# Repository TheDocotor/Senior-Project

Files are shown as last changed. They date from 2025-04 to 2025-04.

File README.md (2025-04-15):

# RC2 Ellipsometer Autoleveling

This repository contains all required documentation for the building and operation of an automated leveling system for in-situ temperature testing on the JA Woolham RC2 Ellipsometer.
Please refer to Ellipsometer_Technical_Design_Document.pdf for full write up of system.

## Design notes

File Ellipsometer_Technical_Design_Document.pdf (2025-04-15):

# Ellipsometer Automated Leveling System

### Technical Design Document

### Garrett Nadauld Ryan Enslow Weber State University Advisor: Dr. Mock

### March 31, 2025

## Contents

1 Introduction | 3
2 Scope | 3
3 Design Overview | 3
4 Testing | 7
5 Conclusion | 8
6 Appendices | 8

## Executive Summary

This project focuses on the design and development of an automated leveling system for the RC2 Ellipsometer, used in precision surface testing. Our primary goal is to reduce workload and speed up testing. The system uses a lookdown detector and servo motors, controlled by a ClearCore microcontroller, to automatically level the test sample.
By automating core functionalities and retaining manual control, our system reduces user workload while maintaining compatibility and precision. The apparatus is removable, integrates easily with existing test setups, and aims to provide a cost-effective alternative to commercial solutions.

## 1 Introduction

The Ellipsometer Automated Leveling System enhances precision and efficiency in aligning samples for ellipsometric measurements. Using a laser-based tilt detection system and servodriven screw adjustments, it minimizes human error and streamlines the alignment process for high-throughput and high-accuracy surface testing.

## 2 Scope

This document details the design of the automated leveling system, including requirements, constraints, design logic, hardware/software implementation, and testing. It excludes user operations and measurement procedures, which are documented separately in the user manual.

## 3 Design Overview

### 3.1 Requirements

Functional Requirements

- Detect sample tilt using a laser and 2D lateral-effect position sensor.
- Automatically adjust leveling screws via servo motors.
- Toggle between manual and automatic leveling modes.
- Interface with ClearCore and USB debugging.

Performance Requirements

- Achieve tilt correction within ±0.2 units in under 3 seconds.
- Maintain level without disrupting measurements.

Interface Requirements

- ClearCore GPIO compatibility.
- Toggle switch for mode selection.

### 3.2 Constraints

- Physical: Must mount externally, be removable, and avoid laser path interference.
- Cost: Total system budget under $2,400.
- Power: Operates from two 24V DC with step-down converters.
- Safety: Laser beam intensity attenuated via ND filter.
- Time: Completion within two academic semesters.

### 3.3 Dependencies

- External 120V AC power source
- Flat, reflective sample surface
- Microchip Studio with ClearCore SDK
- USB programming interface

### 3.4 Theory of Operation

A 635 nm laser reflects off the sample surface onto a ThorLabs PDP90A lateral-effect sensor. The sensor detects displacement from level, which the ClearCore controller uses to compute necessary corrections. It sends commands to ClearPath servo motors that adjust the sample’s leveling screws via a belt drive.

### 3.5 Design Alternatives

### 3.5.1 Motor Selection

Stepper motors were initially considered due to their low cost and simplicity. However, they were ultimately rejected because they lack closed-loop feedback and are prone to missed steps, especially under load. To ensure reliable and precise alignment, servo motors with integrated control logic were selected instead.
The chosen ClearPath-SD servo motors feature a Step & Direction interface compatible with the Teknic ClearCore controller. These servos include automatic tuning capabilities that optimize performance for the specific application and load. Their integrated design eliminates the need for separate motor driver wiring, reducing system complexity and potential failure points.
Other advantages include:

- Closed-loop positioning, which eliminates concerns about missed steps
- Whisper-quiet operation, avoiding the audible whine typical of stepper motors

### 3.5.2 Sensor Selection

Quadrant Position Photodiode Detectors (QPDs), such as the ThorLabs PDQ80A and PDQ30C, were considered as potential alternatives due to their ability to determine beam displacement by comparing photocurrent across segmented regions. However, these detectors rely on intensity profiling and segmented detection, which inherently limits their resolution and introduces nonlinearity, particularly near quadrant boundaries.
The ThorLabs PDP90A 2D lateral-effect sensor was ultimately selected for its superior linearity, continuous position output, and cost-effective design. Unlike QPDs, the PDP90A operates using a tetra-lateral position-sensing mechanism, where photocurrent is distributed proportionally across a resistive layer and four corner-mounted electrodes. This “pincushion” design enables highly linear performance across the 9 mm × 9 mm active area, with accuracy comparable to more expensive duo-lateral sensors.
Additional advantages of the PDP90A include:
- Analog output in both X and Y axes, ideal for continuous feedback loops
- High resolution suitable for precision optical alignment tasks
- Compatibility with the 635 nm laser wavelength used in the system
- Cost-effective alternative to duo-lateral designs due to simplified structure

These characteristics made the PDP90A an optimal choice for accurate and responsive tilt detection in the automated leveling application.

### 3.5.3 Laser Selection

The PL204 laser module from ThorLabs was selected as the light source for this system. The key factors influencing this decision were:

- Cost: The PL204 is a cost-effective, off-the-shelf component with sufficient beam quality and output power for position-sensing applications.
- Wavelength Compatibility: Operating at 635 nm, the laser falls well within the operating range of the PDP90A lateral-effect sensor, which supports wavelengths from 320 nm to 1100 nm. This ensures reliable detection and signal strength without oversaturating the sensor.

An alternative considered was a tunable laser source. Such a laser would have allowed precise adjustment of output power and wavelength to potentially improve the resolution and signal-to-noise ratio of the PDP90A. However, tunable lasers are significantly more expensive and complex to integrate, and the marginal gains in resolution did not justify the increased cost and design complexity for this application.
The PL204 thus provided a practical balance between performance, simplicity, and cost.

### 3.6 Software

The program SeniorProject.cpp implements an automatic leveling system for a J.A. Woollam RC2 Ellipsometer. The system uses a lateral effect position-sensing detector and a laser to monitor the position of the beam reflected from the sample surface. Based on the beam’s displacement, the program computes if the test bed has deviated from its leveled position. If it has, two ClearCore-controlled stepper motors make precise adjustments in the X and Y directions to restore the correct alignment.
The software runs continuously on the Teknic ClearCore microcontroller. It averages voltage readings from three analog inputs (X, Y, and SUM) and determines whether any deviation from a previously recorded level position exceeds a defined tolerance threshold. When the “leveling” switch is turned on, the system records the current position as the baseline and proceeds to adjust the motor position if deviations are detected. The program alternates between checking X and Y directions, with a 75 ms delay between each sample set.
Safety mechanisms include automatic motor alert handling and LED indicators to warn if the laser signal is lost. The system disables motors when not actively leveling, allowing manual adjustment.

### 3.7 Function Descriptions

### main()

The main function initializes the hardware configuration and enters a loop that:

- Reads analog voltages from three ClearCore connectors.
- Converts these voltages to floating-point values for processing.
- Averages 10 samples to reduce noise.
- If the system is in ”leveling” mode, it:

– Enables the motors.

– Sets a reference level position if it’s the first loop.

– Checks if the laser is off the sensor (low SUM voltage).

– If the sample has shifted beyond X or Y tolerance, moves the motors accordingly.

- If not leveling, it disables the motors.

### MoveDistanceX(int32 t distance)

This function moves the X-axis motor by a specified number of step pulses. It:

- Checks if there is a motor alert and handles it.
- Sends a move command to the motor.

- Waits for the motor’s HLFB (High-Level Feedback) to assert that the move is complete.

This function enables precise micro-adjustments based on laser deviations in the X direction.

### MoveDistanceY(int32 t distance)

Same as MoveDistanceX, but for the Y-axis motor. Ensures the Y adjustment happens only if it is safe to do so.

### HandleAlertsX()

This function resets fault conditions for the X-axis motor. It:

- Disables the motor momentarily.
- Waits 10 ms.
- Re-enables the motor and clears all alerts.

Used to recover from faults like overload or signal loss.

### HandleAlertsY()

Identical in structure to HandleAlertsX(), but for the Y motor. Keeps the system in a recoverable state after motor errors.

### 3.8 Power System

- Laser Power: The PL204 laser module requires a regulated 5V supply. A DC-DC converter is used to step down from the 24V system voltage to 5V.
- Sensor Power: The PDP90A sensor requires a split supply of ±5V. A dedicated DC-DC converter is used to generate this bipolar voltage from a 24V input.
- Motor Isolation: The ClearPath-SD motors are powered by a separate 24V power supply, isolated from the logic and sensor power domains. This prevents noise and back EMF from interfering with sensitive analog circuitry.

## 4 Testing

Test | Procedure | Expected Result | Requirement Verified
Sensor Detection | Manually tilt sample | Beam offset de-tected | Functional

Motor Adjustment | Enable auto with tilt present | Leveling completes in ¡3s | Performance
Manual Switch | Flip toggle to manual | Disables auto mode | Interface
System Safety | Power cycle during test | Motors halt safely | Constraint

## 5 Conclusion

The system meets all major design requirements, providing consistent and quick leveling without affecting the operation of the ellipsometer. While not being able to level maintain the sample level within 0.2 units it still provides a significant increase in performance compared to results without the system. The servo-based mechanism and ClearCore controller delivered reliable performance in lab testing. Future improvements include GUI integration, wireless controls, using the software level for adjustments, and beam positioning testing.

## 6 Appendices

### 6.1 Wiring Diagram

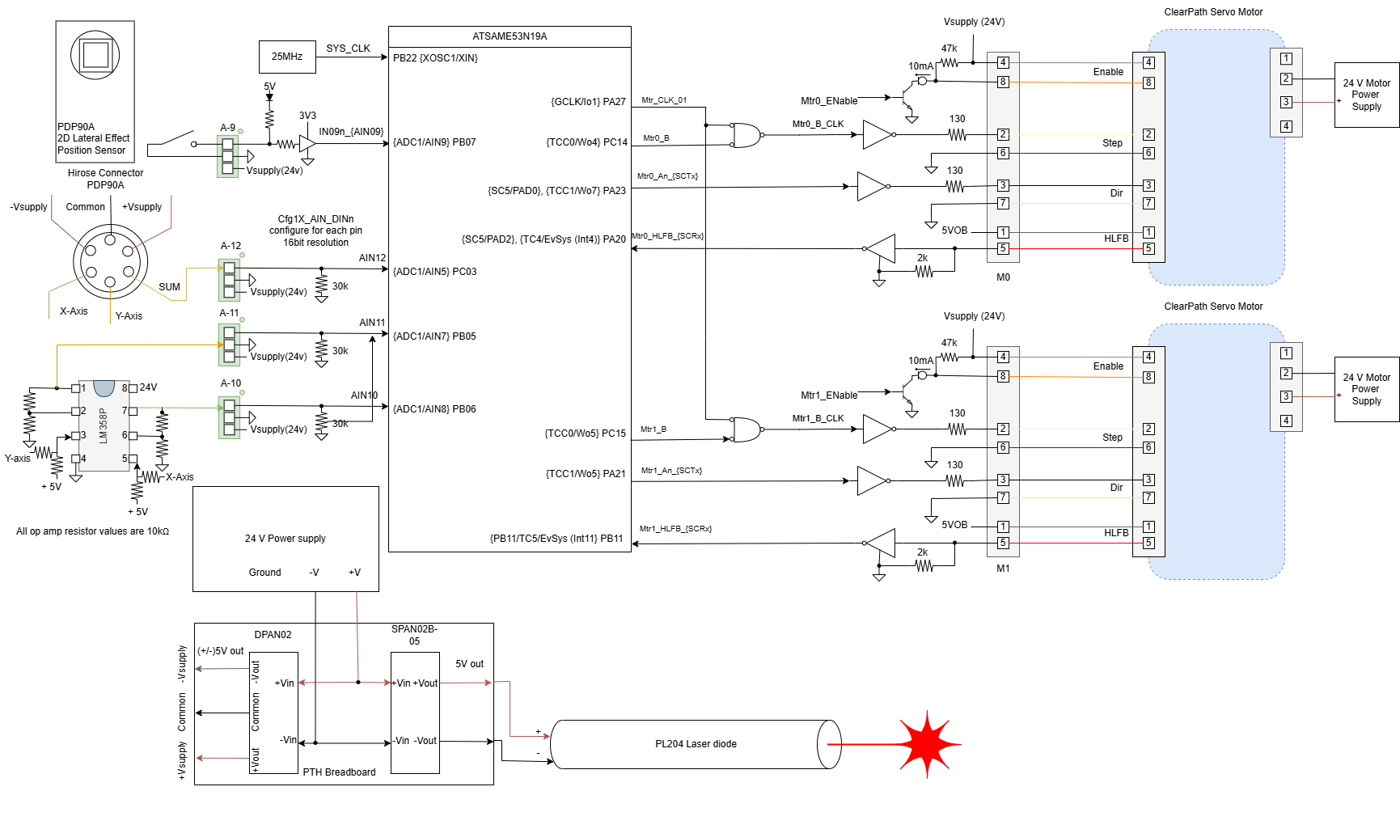
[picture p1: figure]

Figure 1: Full System Wiring Diagram

### 6.2 Source Code

All source code can be found at: https://github.com/TheDocotor/Senior-Project

### 6.2.1 C++

- SeniorProject.cpp (main) - Used in normal operation of leveling. No serial output.
- SeniorProject.cpp (SerialPrint) - Used in conjunction with EllipData.py to send voltage information from clear core and compiles data into a CSV that chan be processed by SerialData.py.

### 6.2.2 Python

- EllipData.py - Used to gather the serial data from the ClearCore. Compiles the data into a CSV that can be processed by SerialData.py
- CompleteEase.py - Used to plot the level data as seen in the CompleteEase Software. Useful to average multiple runs or compare runs to original alignment prior to installation of the system.
- SerialData.py - Used to plot the position on the sensor based on data collected by EllipData.py. Also provides standard deviation, mean and max deviation from center.

### 6.3 CAD Files

The following CAD files are included in the project archive and can be found at: https://github.com/TheDocotor/Senior-Project

- TopMount.stl – 3D-printed bracket for sensor and laser
- TopMount.step – 3D-printed bracket for sensor and laser
- MotorMountX.stl – Servo motor mount for X
- MotorMountX.step – Servo motor mount for X
- MotorMountY.stl – Servo motor mount for Y
- MotorMountY.step – Servo motor mount for Y
- AdjustmentKnob.stl – Cap for adjustment knobs
- AdjustmentKnob.step – Cap for adjustment knobs

### 6.4 Component Datasheets

All data sheets are included in the project archive and can be found at: https://github.com/TheDocotor/Senior-Project

### 6.5 Bill of Materials

Component | Part Number | Qty | Notes
PDP90A Sensor | PDP90A | 1 | Lateral-effect sensor
PL204 Laser | PL204 | 1 | 635 nm beam
Absorptive ND Filter | NE510A | 1 | 25% light transmission
DC-DC Converter (5V) | SPAN02B-05 | 1 | 24V to 5V
DC-DC Converter (±5V) | DPBW03F-05 | 1 | 24V to ±5V
ClearCore Controller | CLCR-4-13 | 1 | Motion and I/O control
Atmel-ICE Debugger | ATATMEL-ICE-BASIC | 1 | Debugger for ClearCore
Atmel-ICE to ClearCore | TC2030-CTX-LEMTA | 1 | Cable for debugger
ClearPath Servo Motors | CPM-SDSK-2310D-ELN | 2 | Level adjustments
Power Supply | LRS-150-24 | 2 | 24V DC supplies
Op-Amp | 296-1395-5-ND | 1 | Sensor voltage offset
3D Printed Mounts | – | 5 | Sensor, laser, motor, and
adjustment knob models
2-Pin Molex Plug | WM20244-ND | 2 | Modular | connector | for
| | | laser
2-Pin Molex RCPT | WM13486-ND | 2 | Companion to 2-pin plug
4-Pin Molex Plug | WM16259-ND | 3 | For motor power cabling
4-Pin Molex RCPT | WM16165-ND | 1 | Companion to 4-pin male
8-Pin Molex Plug | WM26395-ND | 5 | Motor | control | to
| | | ClearCore
8-Pin Molex RCPT | WM13488-ND | 1 | Companion to 8-pin male
Terminal Block Plugs | CC-3TERM-PLUG-10PC | 5 | Companion to 8-pin male
Switch | – | 2 | Toggles for power and lev-
eling control
Hirose RCPT (F) 6P | HR1594-ND | 1 | For sensor to enclosure
Drive Belt | 124L050NG | 2 | Belt to connect motor
shaft to adjustment knob
Timing Pulley | APB13L050BF-375 | 2 | Conenction point for the
motor shaft
Power Receptacle | CCM1784-ND | 1 | Power cable receptacle
Power Cable | Q988-ND | 1 | Cable for wall outlet

Table 2: Bill of Materials

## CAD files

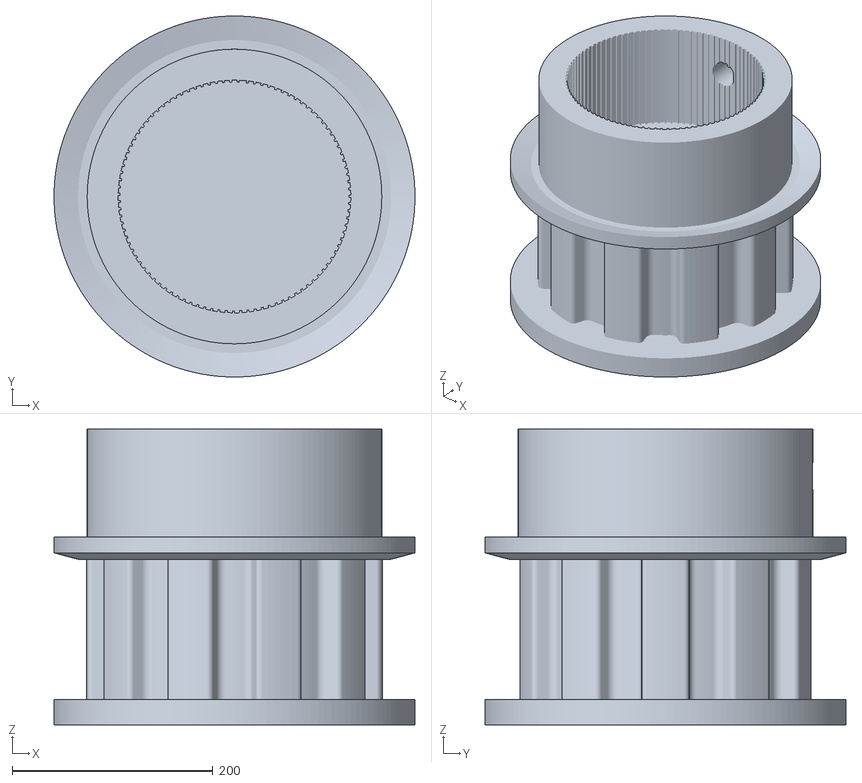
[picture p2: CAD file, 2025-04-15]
3Dprint files/AdjustmentKnob.stl
360.0 x 360.0 x 294.8

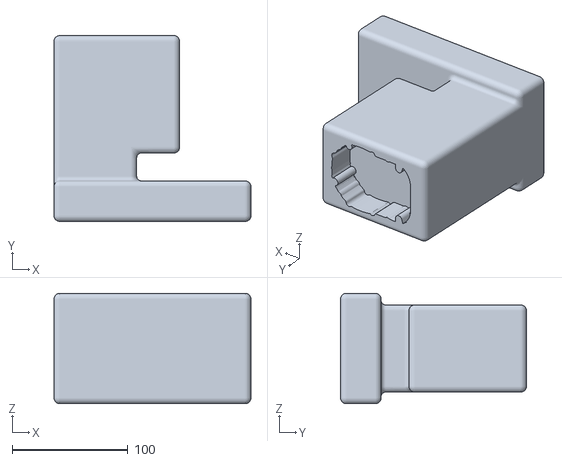
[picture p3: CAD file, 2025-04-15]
3Dprint files/MotorMountY.stl
170.0 x 160.4 x 95.2

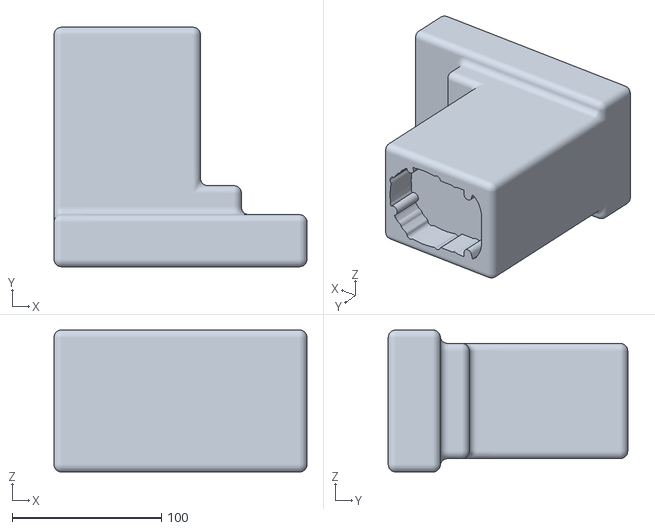
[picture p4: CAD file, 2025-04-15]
3Dprint files/MotorMountX.stl
169.7 x 160.7 x 95.2

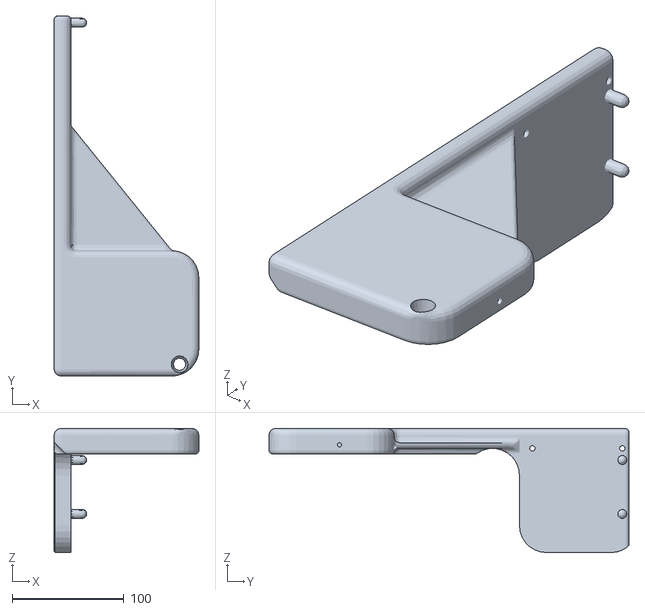
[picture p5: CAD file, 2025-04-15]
3Dprint files/TopMount.stl
129.6 x 322.2 x 111.0

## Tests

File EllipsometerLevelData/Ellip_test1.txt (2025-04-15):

Parameters vs. Time
Time (min.)	AlignX	AlignY	Temperature(C)
0.118583	-0.041280	-0.026336	24.836016	
0.172583	0.020837	-0.021236	25.014530	
0.226583	0.045690	0.034902	25.296223	
0.280583	0.085720	0.096434	25.885847	
0.334617	0.109744	0.151967	26.524569	
0.388617	0.189993	0.230251	27.327288	
0.442650	0.228375	0.313507	28.179588	
0.496650	0.295306	0.290474	29.137653	
0.550683	0.395386	0.091753	30.176928	
0.604717	0.393161	0.128371	31.230230	
0.658683	0.395943	0.143892	32.255962	
0.712683	0.397930	0.184818	33.403984	
0.766717	0.429667	0.263335	34.405983	
0.820683	0.286139	-0.026264	35.376667	
0.874717	0.331988	-0.093079	36.448162	
0.928517	0.360934	-0.028123	37.490608	
0.982317	0.417613	0.018809	38.557739	
1.036183	0.431605	-0.058537	39.533081	
1.090083	0.495320	-0.231804	40.532272	
1.144117	0.502457	-0.158535	41.504047	
1.198117	0.536670	-0.150594	42.480343	
1.252117	0.549993	-0.108000	43.497299	
1.306117	0.566278	-0.049375	44.394398	
1.360183	0.457136	-0.012867	45.321918	
1.414150	0.484191	-0.161352	46.321804	
1.468183	0.485045	-0.334342	47.276814	
1.522217	0.529164	-0.299895	48.199162	
1.576217	0.524435	-0.207020	49.158245	
1.630250	0.596894	-0.150165	50.118965	
1.684250	0.479925	-0.168618	50.968613	
1.738250	0.420639	-0.176686	51.953495	
1.792317	0.456555	-0.390947	52.935402	
1.846117	0.502611	-0.399960	53.884766	
1.899950	0.519346	-0.318151	54.742939	
1.953883	0.516156	-0.271888	55.674828	
2.007917	0.487114	-0.267040	56.497173	
2.061783	0.386563	-0.198937	57.497993	
2.115817	0.412487	-0.426013	58.301781	
2.169850	0.440590	-0.488537	59.202728	
2.223850	0.462063	-0.416323	60.109184	
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

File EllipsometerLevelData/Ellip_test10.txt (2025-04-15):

Parameters vs. Time
Time (min.)	AlignX	AlignY	Temperature(C)
0.168117	-0.011810	0.001451	24.131662	
0.222150	-0.006528	0.029344	24.490301	
0.276183	-0.044197	0.056674	24.938715	
0.330183	-0.056247	0.091909	25.522610	
0.384217	-0.008409	0.138111	26.258095	
0.438217	0.072713	0.105040	26.930157	
0.492217	-0.070123	0.145629	28.002691	
0.546250	-0.019005	-0.068894	28.866596	
0.600250	0.036046	-0.045884	29.905478	
0.654283	0.054328	-0.129453	30.854378	
0.708317	-0.064122	-0.258034	32.006828	
0.762317	-0.030392	-0.189520	32.986050	
0.816383	0.048420	-0.145151	34.075123	
0.870383	-0.071720	-0.125145	35.070518	
0.924417	-0.063865	-0.418252	36.225433	
0.978450	-0.166068	-0.363490	37.162262	
1.032450	-0.112328	-0.294412	38.124954	
1.086483	-0.099591	-0.430787	39.207615	
1.140450	-0.042349	-0.510560	40.190948	
1.194483	-0.108072	-0.486803	41.127972	
1.248517	-0.124357	-0.447834	42.130466	
1.302583	-0.096240	-0.651262	43.139202	
1.356650	-0.105625	-0.880548	44.017303	
1.410650	-0.251906	-0.802809	45.038170	
1.464683	-0.227095	-0.780231	46.062355	
1.518483	-0.236412	-0.987779	46.964535	
1.572317	-0.210413	-1.046481	47.967842	
1.626150	-0.383966	-1.397967	48.803471	
1.680183	-0.425216	-1.260316	49.796967	
1.734117	-0.380085	-1.224725	50.692398	
1.788050	-0.324533	-1.142400	51.627678	
1.842050	-0.378494	-1.135248	52.478645	
1.896083	-0.444369	-1.126213	53.482811	
1.949917	-0.510781	-1.078143	54.453556	
2.003750	-0.537672	-0.906426	55.338276	
2.057617	-0.492028	-0.853576	56.233845	
2.111617	-0.460295	-0.837870	57.061295	
2.165650	-0.439806	-0.850249	57.997799	
2.219783	-0.379291	-0.693380	58.990204	
2.273817	-0.404685	-0.758148	59.854618	
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

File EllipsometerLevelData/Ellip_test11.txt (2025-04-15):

Parameters vs. Time
Time (min.)	AlignX	AlignY	Temperature(C)
0.168583	-0.046639	-0.376566	20.884941	
0.222450	-0.041730	-0.349978	21.162317	
0.276417	-0.001431	-0.278168	21.518782	
0.330417	0.038545	-0.223533	22.094357	
0.384483	0.063708	-0.159545	22.917393	
0.438517	0.133346	-0.065030	23.665125	
0.492517	0.035776	-0.043938	24.598125	
0.546517	0.053317	0.023088	25.586304	
0.600517	0.118323	0.109434	26.561781	
0.654583	0.158599	0.137310	27.599186	
0.708583	0.038523	-0.118925	28.714796	
0.762583	-0.062618	-0.378510	29.634850	
0.816650	0.022626	-0.171334	30.757421	
0.870650	0.151670	-0.004082	31.759705	
0.924683	0.196825	0.090223	32.845123	
0.978817	0.165235	0.035145	33.888222	
1.032817	0.158794	0.043298	34.971466	
1.086817	0.229893	0.129744	35.921383	
1.140850	0.105978	-0.200749	36.998730	
1.194883	0.137041	-0.111148	37.975357	
1.248783	0.137578	-0.084488	38.939793	
1.302850	0.212065	-0.040451	39.980690	
1.356883	0.214735	0.027018	40.910282	
1.410883	0.232494	0.117401	41.782413	
1.464883	0.233183	0.207164	42.756306	
1.518917	0.263842	0.276724	43.788090	
1.572917	0.323576	0.109497	44.705631	
1.626917	0.339388	0.194124	45.713520	
1.680950	0.384755	0.211036	46.629547	
1.734983	0.294094	0.277594	47.503315	
1.789083	0.323616	0.286995	48.505264	
1.843083	0.305321	0.162863	49.377228	
1.897083	0.328178	0.215307	50.297901	
1.951083	0.258381	0.117444	51.302830	
2.005117	0.155571	0.015098	52.160259	
2.059117	0.188302	0.123254	53.103508	
2.113117	0.253333	0.187550	54.007843	
2.167150	0.274996	0.063613	54.915260	
2.221183	0.293713	-0.089819	55.800106	
2.275183	0.343788	0.085302	56.771717	
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

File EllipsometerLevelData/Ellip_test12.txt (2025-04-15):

Parameters vs. Time
Time (min.)	AlignX	AlignY	Temperature(C)
0.167683	0.067166	0.083648	23.120749	
0.221683	0.099483	0.093399	23.369642	
0.275650	0.118718	0.118501	23.757235	
0.329683	0.154895	0.178274	24.320704	
0.383683	0.220688	0.250243	25.049406	
0.437717	0.275300	0.258517	25.837414	
0.491717	0.297653	-0.060186	26.783432	
0.545750	0.330778	-0.161729	27.773209	
0.599783	0.354492	-0.043041	28.722492	
0.653783	0.262545	0.019468	29.715990	
0.707783	0.315992	0.082061	30.708815	
0.761850	0.381151	0.170664	31.884439	
0.815850	0.385087	-0.091623	32.818520	
0.869883	0.400611	-0.013517	33.989388	
0.923883	0.326587	0.032991	34.935841	
0.977883	0.350955	0.109889	36.012627	
1.031917	0.256558	0.171326	36.992962	
1.085917	0.260346	0.175757	37.986538	
1.139783	0.320190	-0.077792	39.035965	
1.193617	0.361817	0.005636	40.099243	
1.247450	0.340193	0.060590	41.077709	
1.301383	0.257872	0.131732	41.973297	
1.355383	0.282924	0.251629	42.978252	
1.409383	0.341448	0.022576	43.933132	
1.463383	0.356389	0.061620	44.911144	
1.517383	0.397805	0.081188	45.806206	
1.571283	0.201648	-0.137315	46.694366	
1.625317	0.216240	-0.028492	47.663288	
1.679317	0.058627	0.018462	48.621838	
1.733350	0.098453	-0.143214	49.623798	
1.787150	0.134544	-0.148360	50.474148	
1.841017	0.163277	-0.045786	51.457523	
1.894917	0.221606	0.011050	52.319489	
1.948850	0.262482	-0.039665	53.241241	
2.002850	0.091184	-0.224139	54.193779	
2.056883	0.076237	-0.112077	55.162113	
2.110883	0.198861	-0.051518	55.998070	
2.164717	0.112765	0.081392	56.849998	
2.218550	-0.012815	0.101781	57.758308	
2.272417	-0.167110	0.133754	58.739014	
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

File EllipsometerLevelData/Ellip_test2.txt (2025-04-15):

Parameters vs. Time
Time (min.)	AlignX	AlignY	Temperature(C)
0.168550	0.064122	0.044254	23.076591	
0.222550	0.084154	0.069582	23.364233	
0.276583	0.096145	0.118140	23.672337	
0.330583	0.168860	0.189502	24.302608	
0.384583	0.195827	0.257248	25.106260	
0.438583	0.227606	0.325688	25.875063	
0.492583	0.290378	0.416597	26.773712	
0.546583	0.311054	0.470335	27.701771	
0.600583	0.384512	0.590589	28.658625	
0.654617	0.405680	0.656004	29.751350	
0.708617	0.464308	0.715677	30.836828	
0.762650	0.505908	0.295842	31.893223	
0.816650	0.500468	0.393966	32.927197	
0.870683	0.552007	0.444180	34.018406	
0.924717	0.506079	0.517580	35.065228	
0.978750	0.457472	0.593879	35.991074	
1.032750	0.447968	0.676628	37.085220	
1.086783	0.522618	0.755370	38.086594	
1.140783	0.460573	0.847435	39.091526	
1.194783	0.374429	0.913129	40.006828	
1.248617	0.359926	0.790073	41.054150	
1.302417	0.426413	0.607261	42.035633	
1.356250	0.437331	0.648894	42.999187	
1.410250	0.522175	0.763229	43.881397	
1.464283	0.538267	0.567326	44.904099	
1.518250	0.390486	0.551536	45.884445	
1.572250	0.359735	0.642182	46.859360	
1.626317	0.431231	0.647077	47.723289	
1.680317	0.420001	0.723394	48.708366	
1.734350	0.476617	0.757418	49.611774	
1.788350	0.521664	0.608051	50.630070	
1.842350	0.571742	0.532589	51.493752	
1.896350	0.557687	0.615059	52.484177	
1.950350	0.443749	0.694331	53.339653	
2.004350	0.411256	0.501339	54.241287	
2.058350	0.432278	0.382363	55.134014	
2.112383	0.427113	0.399191	56.039650	
2.166250	0.487631	0.523825	57.035408	
2.220083	0.532069	0.590680	57.783031	
2.273917	0.523078	0.663774	58.715611	
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

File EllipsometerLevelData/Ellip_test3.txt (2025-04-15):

Parameters vs. Time
Time (min.)	AlignX	AlignY	Temperature(C)
0.167883	0.059796	-0.014691	23.007935	
0.221883	0.040957	0.020164	23.400824	
0.275917	0.080487	0.055859	23.930487	
0.329917	0.138778	0.117553	24.467409	
0.383917	0.188876	0.171581	25.170792	
0.437917	0.222484	0.257854	26.044857	
0.491950	0.308227	0.317970	27.017944	
0.545950	0.340746	0.385676	27.969851	
0.599983	0.346464	0.414496	29.017851	
0.653983	0.385103	0.474481	30.023184	
0.707983	0.387339	0.569224	31.035904	
0.761983	0.293574	0.577176	32.113567	
0.815950	0.316778	0.618829	33.130001	
0.869983	0.345379	0.651212	34.102303	
0.924017	0.360201	0.696558	35.217216	
0.978050	0.392810	0.732926	36.271786	
1.032050	0.428314	0.775259	37.293545	
1.086083	0.201085	0.765618	38.332333	
1.140117	0.260594	0.820848	39.280319	
1.194117	0.268870	0.866119	40.345001	
1.248117	0.249264	0.878686	41.275478	
1.302117	0.276686	0.948887	42.276386	
1.356150	0.141603	0.961982	43.239941	
1.410150	0.075218	0.981680	44.184528	
1.464183	0.138480	1.003076	45.123096	
1.518183	0.188208	1.035988	46.003750	
1.571983	0.185533	1.051620	47.054279	
1.625783	0.225736	1.096398	47.964714	
1.679583	0.268127	1.162743	48.864876	
1.733683	0.253632	1.211878	49.849255	
1.787650	0.290676	1.281211	50.741539	
1.841617	0.343024	1.349752	51.699059	
1.895550	0.367067	1.217065	52.598358	
1.949583	0.222444	0.955607	53.468552	
2.003583	0.230825	1.028350	54.449013	
2.057417	0.207331	1.094818	55.328953	
2.111250	0.266170	1.008512	56.277622	
2.165117	0.281910	0.627894	57.197071	
2.219183	0.307585	0.689762	58.060802	
2.273250	0.329247	0.819358	58.979935	
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

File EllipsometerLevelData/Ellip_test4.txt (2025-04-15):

Parameters vs. Time
Time (min.)	AlignX	AlignY	Temperature(C)
0.168117	-0.159759	-0.051092	23.545778	
0.222117	-0.121864	-0.006964	23.853886	
0.276117	-0.039485	0.041802	24.291838	
0.330183	-0.005436	0.122777	24.952137	
0.384183	0.038613	0.179799	25.692701	
0.438217	0.090251	0.224776	26.424063	
0.492217	0.142805	0.199326	27.391798	
0.546250	0.207975	-0.030446	28.357115	
0.600250	0.066992	-0.052697	29.391010	
0.654283	0.077049	0.040706	30.395596	
0.708283	0.166181	0.122196	31.438900	
0.762317	0.221251	-0.193855	32.585186	
0.816317	0.102373	-0.483424	33.510269	
0.870350	0.024758	-0.573369	34.528046	
0.924383	0.097083	-0.887861	35.598000	
0.978483	0.151934	-0.824206	36.692944	
1.032517	0.187432	-0.758834	37.700146	
1.086350	0.211541	-0.698583	38.697430	
1.140183	0.244837	-0.631527	39.650738	
1.193983	0.323127	-0.571854	40.680061	
1.247850	0.142598	-0.487012	41.615726	
1.301883	0.135677	-0.423702	42.684086	
1.355917	0.164734	-0.544646	43.493248	
1.409950	0.241226	-0.719461	44.512138	
1.463983	0.085799	-0.680182	45.575100	
1.517983	0.103077	-0.587683	46.437210	
1.572017	0.096536	-0.534007	47.494221	
1.626050	0.164141	-0.463292	48.381443	
1.680083	0.106843	-0.578407	49.336983	
1.733917	0.045158	-0.705177	50.229389	
1.787717	0.027569	-0.671933	51.169361	
1.841683	0.072004	-0.614158	52.094093	
1.895650	0.113164	-0.526763	52.969128	
1.949683	0.163786	-0.756648	53.850544	
2.003583	-0.057973	-0.816603	54.733273	
2.057617	0.009080	-0.754031	55.748718	
2.111650	0.023305	-0.662104	56.646709	
2.165650	0.099721	-0.561163	57.471622	
2.219683	-0.112410	-0.578217	58.430157	
2.273683	-0.074311	-0.487330	59.355824	
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

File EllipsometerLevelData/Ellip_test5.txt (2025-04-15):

Parameters vs. Time
Time (min.)	AlignX	AlignY	Temperature(C)
0.167983	-0.076667	-0.191341	20.804811	
0.222050	-0.081573	-0.145919	21.121300	
0.276050	-0.021468	-0.081199	21.553493	
0.330083	0.043089	-0.025818	22.146378	
0.384083	0.069431	0.038467	22.855862	
0.438083	0.146418	0.148461	23.753830	
0.492117	0.200716	0.213696	24.675892	
0.546117	0.193668	0.262679	25.590517	
0.600117	0.206699	0.350630	26.572176	
0.654417	0.207351	0.543864	27.651703	
0.708450	0.141182	0.712361	28.604874	
0.762450	0.080351	0.301201	29.783918	
0.816283	0.079990	0.100347	30.802832	
0.870117	0.109127	0.173667	31.861803	
0.923983	0.164330	0.254552	32.884254	
0.977817	0.000269	0.337138	33.974773	
1.031850	0.046532	0.400591	34.909222	
1.085883	0.077285	0.468302	35.910408	
1.139717	0.167170	0.591548	36.991547	
1.193517	0.193960	0.602034	37.958923	
1.247483	0.056884	0.248985	38.881317	
1.301483	0.152391	0.284864	39.894215	
1.355483	-0.035698	0.328168	40.931438	
1.409450	0.000405	0.383018	41.818768	
1.463483	0.040254	0.466596	42.782738	
1.517517	0.068058	0.531205	43.773575	
1.571517	0.020951	0.561536	44.724369	
1.625517	-0.043456	0.661989	45.625404	
1.679583	0.006958	0.701401	46.579109	
1.733583	-0.007166	0.796166	47.491001	
1.787583	0.047196	0.545634	48.485729	
1.841617	0.083832	0.563669	49.424778	
1.895617	0.026955	0.621724	50.439388	
1.949650	-0.076557	0.639486	51.272984	
2.003683	-0.052532	0.710271	52.228474	
2.057717	-0.172359	0.758185	53.130371	
2.111717	-0.148690	0.448371	53.944546	
2.165750	-0.114878	0.600290	55.022148	
2.219850	-0.069715	0.574030	55.897518	
2.273850	-0.007283	0.696237	56.755867	
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

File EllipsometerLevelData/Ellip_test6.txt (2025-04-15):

Parameters vs. Time
Time (min.)	AlignX	AlignY	Temperature(C)
0.168350	0.012503	-0.045072	23.366922	
0.222383	0.058204	0.016916	23.712725	
0.276383	0.078522	0.084630	24.084286	
0.330383	0.160079	0.141154	24.817160	
0.384383	0.222019	0.219732	25.412546	
0.438417	0.256595	0.289606	26.335854	
0.492417	0.298227	0.334433	27.182055	
0.546417	0.343839	0.403378	28.232407	
0.600417	0.431053	0.462949	29.231056	
0.654450	0.488599	0.506293	30.318361	
0.708450	0.537928	0.574704	31.335701	
0.762450	0.501252	0.623001	32.502716	
0.816450	0.452277	0.639700	33.452007	
0.870450	0.437977	0.660352	34.433239	
0.924450	0.387990	0.747374	35.521465	
0.978550	0.414722	0.838795	36.612404	
1.032350	0.466352	0.817842	37.672897	
1.086183	0.382573	0.850791	38.589214	
1.140017	0.405363	0.911679	39.593868	
1.193883	0.425443	0.780993	40.549122	
1.247917	0.442496	0.735830	41.541344	
1.301917	0.390037	0.773940	42.577038	
1.355917	0.427240	0.735281	43.513718	
1.410050	0.469492	0.767106	44.410282	
1.464050	0.450537	0.824080	45.465694	
1.518050	0.446454	0.837747	46.438923	
1.572050	0.471846	0.687970	47.271210	
1.626017	0.441734	0.721209	48.295471	
1.680050	0.465288	0.710917	49.129810	
1.734083	0.541374	0.627993	50.043877	
1.788083	0.523407	0.710552	51.065163	
1.841950	0.526790	0.690321	51.929909	
1.895750	0.596079	0.700014	52.863701	
1.949617	0.523849	0.647917	53.765163	
2.003650	0.520834	0.655850	54.744179	
2.057650	0.518485	0.604754	55.641891	
2.111650	0.528391	0.546968	56.539700	
2.165550	0.572923	0.571627	57.398674	
2.219383	0.655370	0.615005	58.348583	
2.273217	0.617878	0.718317	59.222202	
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

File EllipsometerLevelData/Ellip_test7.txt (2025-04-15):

Parameters vs. Time
Time (min.)	AlignX	AlignY	Temperature(C)
0.168250	-0.027829	-0.032359	25.929928	
0.222250	-0.037286	0.022315	26.196381	
0.276250	0.042388	0.084993	26.449699	
0.330250	0.075819	0.175859	27.137159	
0.384250	0.154280	0.239727	27.822018	
0.438283	0.191101	0.327542	28.633804	
0.492283	0.266115	0.395587	29.572218	
0.546317	0.316837	0.476663	30.538511	
0.600117	0.425330	0.111820	31.626875	
0.653950	0.205244	-0.224410	32.672558	
0.707750	0.259915	-0.098556	33.646481	
0.761750	0.325905	0.000408	34.729103	
0.815650	0.291199	0.031974	35.734646	
0.869650	-0.023409	0.087412	36.683899	
0.923717	0.018204	0.186022	37.787704	
0.977517	0.086185	0.262163	38.870899	
1.031350	0.147842	0.321506	39.870235	
1.085317	0.214033	0.412141	40.855270	
1.139317	0.288253	-0.124445	41.850380	
1.193250	0.304225	-0.271320	42.845901	
1.247250	0.398318	-0.199855	43.812439	
1.301283	0.458550	-0.106738	44.809139	
1.355283	0.395366	-0.097674	45.765182	
1.409350	0.027771	0.013558	46.704742	
1.463383	0.112575	0.125619	47.656937	
1.517383	0.159279	0.157883	48.727081	
1.571383	0.239559	0.214976	49.589863	
1.625417	0.247999	-0.476042	50.496117	
1.679450	0.291144	-0.323025	51.422417	
1.733450	0.360516	-0.278976	52.341068	
1.787250	0.120275	-0.321880	53.350189	
1.841083	-0.011908	-0.216041	54.143291	
1.894917	0.017096	-0.086802	55.128277	
1.948917	-0.001870	0.018646	56.014702	
2.002917	0.086830	0.108629	56.946079	
2.056883	0.119535	0.080401	57.811653	
2.110883	0.204391	0.068459	58.708797	
2.164917	0.248940	0.141027	59.627735	
2.218883	0.314844	-0.549886	60.539127	
2.272883	0.355206	-0.488462	61.385387	
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

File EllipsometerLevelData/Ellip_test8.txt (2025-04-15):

Parameters vs. Time
Time (min.)	AlignX	AlignY	Temperature(C)
0.168117	0.273241	-0.450605	34.601067	
0.222117	0.286929	-0.374474	35.244831	
0.276117	0.322211	-0.318168	35.914604	
0.330117	0.384363	-0.255384	36.659809	
0.384150	0.369670	-0.134778	37.608662	
0.438150	0.347474	-0.115301	38.450661	
0.492150	0.077016	-0.140343	39.353077	
0.546150	0.116144	-0.037796	40.286282	
0.600150	0.090736	-0.077616	41.186157	
0.654183	0.112661	-0.718573	42.045170	
0.708183	0.121216	-0.621470	42.965523	
0.762217	0.176101	-0.564169	44.007957	
0.816250	0.217901	-0.521904	44.814159	
0.870050	0.259375	-0.433345	45.792927	
0.923983	0.280409	-0.402595	46.714561	
0.977783	0.322660	-0.306625	47.593243	
1.031683	0.365718	-0.235429	48.552593	
1.085583	0.395753	-0.200129	49.387028	
1.139617	0.446739	-0.905418	50.280754	
1.193650	0.445590	-0.841846	51.168724	
1.247483	0.500621	-0.795557	52.202312	
1.301317	0.475196	-0.711228	52.993122	
1.355183	0.499223	-0.684594	53.913521	
1.409217	0.536568	-0.655004	54.787289	
1.463217	0.605134	-0.557489	55.703526	
1.517250	0.209981	-0.644307	56.588287	
1.571250	0.191484	-0.571431	57.502808	
1.625250	0.235074	-0.410924	58.357430	
1.679317	0.247307	-0.405096	59.220333	
1.733317	0.313414	-0.391526	60.045876	
1.787350	0.373279	-0.943837	60.980625	
1.841350	0.330535	-1.108073	61.825462	
1.895350	0.320967	-0.925872	62.656872	
1.949383	0.312294	-0.971353	63.596455	
2.003417	0.317230	-0.917463	64.497162	
2.057417	0.407723	-0.907388	65.359413	
2.111417	0.450243	-0.792620	66.285065	
2.165417	0.458873	-0.722710	67.108093	
2.219517	0.438692	-0.584393	67.942459	
2.273350	0.495901	-0.532260	68.732628	
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

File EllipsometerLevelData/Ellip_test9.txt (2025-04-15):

Parameters vs. Time
Time (min.)	AlignX	AlignY	Temperature(C)
0.168517	-0.129182	-0.026957	23.159693	
0.222517	-0.083602	-0.013260	23.459278	
0.276517	-0.043476	0.021768	23.756844	
0.330517	-0.007517	0.098577	24.561255	
0.384550	0.046482	0.144173	25.182138	
0.438550	0.087750	0.236344	25.930040	
0.492583	0.148614	0.305725	26.844330	
0.546583	0.200301	0.363226	27.832439	
0.600583	0.269398	0.428308	28.839092	
0.654383	0.295539	0.508980	29.896761	
0.708217	0.342811	0.546262	30.946800	
0.762050	0.400867	0.628695	32.026470	
0.816050	0.404453	0.249857	33.029007	
0.869950	0.137490	0.063209	34.046062	
0.924017	0.171023	0.176244	35.138176	
0.977850	0.204705	0.238554	36.135639	
1.031683	0.276916	0.286426	37.128693	
1.085583	0.340944	0.383698	38.182034	
1.139583	0.326813	0.482152	39.160671	
1.193517	0.382620	0.541260	40.168945	
1.247517	0.425479	0.588238	41.154911	
1.301517	0.467979	0.631684	42.110462	
1.355550	0.547758	0.744567	43.103462	
1.409583	0.590631	0.768913	44.058098	
1.463583	0.595028	0.530676	45.027855	
1.517583	0.052476	0.099588	45.917400	
1.571583	0.370509	0.291230	46.856823	
1.625650	0.418023	0.374987	47.819954	
1.679650	0.419268	0.491675	48.792294	
1.733683	0.469175	0.512173	49.708454	
1.787683	0.453532	0.564948	50.735210	
1.841650	0.508205	0.691620	51.620422	
1.895717	0.554996	0.752252	52.459831	
1.949717	0.613366	0.010938	53.390003	
2.003717	0.674569	0.155528	54.304081	
2.057517	0.646288	0.242334	55.167870	
2.111350	0.654956	0.206607	56.164585	
2.165283	0.726012	0.348862	57.020538	
2.219117	0.729991	0.496632	57.987030	
2.273117	0.606688	0.489127	58.933250	
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

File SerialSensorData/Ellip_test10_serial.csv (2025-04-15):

PC_Timestamp | Device_Time_ms | LevelX | LevelY | inputVoltageX | inputVoltageY | inputVoltageSUM
2025-04-08T17:25:39.958644 | 59880 | 5.369 | 5.934 | 5.372 | 5.939 | 3.151
2025-04-08T17:25:40.708590 | 60630 | 5.369 | 5.934 | 5.374 | 5.937 | 3.153
2025-04-08T17:25:41.459653 | 61381 | 5.369 | 5.934 | 5.369 | 5.941 | 3.151
2025-04-08T17:25:42.210330 | 62132 | 5.369 | 5.934 | 5.373 | 5.942 | 3.153
2025-04-08T17:25:42.961860 | 62882 | 5.369 | 5.934 | 5.370 | 5.936 | 3.153
2025-04-08T17:25:43.713759 | 63633 | 5.369 | 5.934 | 5.376 | 5.942 | 3.154
2025-04-08T17:25:44.464012 | 64384 | 5.369 | 5.934 | 5.375 | 5.938 | 3.153
2025-04-08T17:25:45.214328 | 65134 | 5.369 | 5.934 | 5.372 | 5.937 | 3.152
2025-04-08T17:25:45.963909 | 65885 | 5.369 | 5.934 | 5.369 | 5.938 | 3.153
2025-04-08T17:25:46.716231 | 66636 | 5.369 | 5.934 | 5.376 | 5.935 | 3.154
2025-04-08T17:25:47.467000 | 67387 | 5.369 | 5.934 | 5.379 | 5.937 | 3.152
2025-04-08T17:25:48.217671 | 68137 | 5.369 | 5.934 | 5.377 | 5.939 | 3.153
2025-04-08T17:25:48.967788 | 68888 | 5.369 | 5.934 | 5.376 | 5.934 | 3.153
2025-04-08T17:25:49.718457 | 69639 | 5.369 | 5.934 | 5.378 | 5.938 | 3.153
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

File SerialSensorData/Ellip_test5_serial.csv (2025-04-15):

PC_Timestamp | Device_Time_ms | LevelX | LevelY | inputVoltageX | inputVoltageY | inputVoltageSUM
2025-04-04T17:07:25.854911 | 2495425 | 5.256 | 5.704 | 5.249 | 5.705 | 3.165
2025-04-04T17:07:26.606140 | 2496176 | 5.256 | 5.704 | 5.251 | 5.703 | 3.164
2025-04-04T17:07:27.356281 | 2496927 | 5.256 | 5.704 | 5.251 | 5.708 | 3.164
2025-04-04T17:07:28.108308 | 2497677 | 5.256 | 5.704 | 5.254 | 5.703 | 3.165
2025-04-04T17:07:28.859000 | 2498428 | 5.256 | 5.704 | 5.254 | 5.701 | 3.164
2025-04-04T17:07:29.609129 | 2499179 | 5.256 | 5.704 | 5.250 | 5.703 | 3.166
2025-04-04T17:07:30.360953 | 2499929 | 5.256 | 5.704 | 5.251 | 5.702 | 3.166
2025-04-04T17:07:31.110969 | 2500680 | 5.256 | 5.704 | 5.251 | 5.703 | 3.166
2025-04-04T17:07:31.859981 | 2501431 | 5.256 | 5.704 | 5.250 | 5.700 | 3.165
2025-04-04T17:07:32.612824 | 2502181 | 5.256 | 5.704 | 5.249 | 5.703 | 3.163
2025-04-04T17:07:33.363461 | 2502932 | 5.256 | 5.704 | 5.250 | 5.706 | 3.165
2025-04-04T17:07:34.114032 | 2503683 | 5.256 | 5.704 | 5.251 | 5.699 | 3.166
2025-04-04T17:07:34.865398 | 2504434 | 5.256 | 5.704 | 5.253 | 5.702 | 3.164
2025-04-04T17:07:35.616428 | 2505184 | 5.256 | 5.704 | 5.255 | 5.703 | 3.164
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

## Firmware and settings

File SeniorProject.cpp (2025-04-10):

/*==========================================================
; Program Name: SeniorProject.cpp
;
; Authors: Ryan Enslow & Garrett Nadauld
;
; Description:
; This program provides an auto-leveling system for the RC 2 Ellipsometer
; made by J.A. Woolam. Used in in-situ temperature testing this program
; utilizes a lateral effect sensor and laser to track the deformation of
; the sample being tested. Two Stepper motors X and Y use the data from
; the sensor to adjust the test bed accordingly.
;
; Company: Weber State University
;
;========================================================== */

#include "ClearCore.h"

// Stepper motor set up:
// Options are: ConnectorM0, ConnectorM1, ConnectorM2, or ConnectorM3.

#define motorX ConnectorM0 //motor X is connected to M0 on the clear core
#define motorY ConnectorM1 //motor Y is connected to M1 on the clear core
// This example has built-in functionality to automatically clear motor alerts, 
//  including motor shutdowns. Any uncleared alert will cancel and disallow motion.
// WARNING: enabling automatic alert handling will clear alerts immediately when 
//  encountered and return a motor to a state in which motion is allowed. Before 
//  enabling this functionality, be sure to understand this behavior and ensure 
//  your system will not enter an unsafe state. 
// To enable automatic alert handling, #define HANDLE_ALERTS (1)
// To disable automatic alert handling, #define HANDLE_ALERTS (0)
#define HANDLE_ALERTS (1)
#define inputPin ConnectorIO5
// Define the velocity and acceleration limits to be used for each move
const int32_t velocityLimit = 10000; // 10000pulses per sec
const int32_t accelerationLimit = 10000; //50000 pulses per sec^2


//ADC Set up:
// Defines the bit-depth of the ADC readings (8-bit, 10-bit, or 12-bit)
// Supported adcResolution values are 8, 10, and 12
#define adcResolution 12

int16_t leveling; // State of input switch


// Declares user-defined helper functions.
void MoveDistanceX(int32_t distance);
void MoveDistanceY(int32_t distance);
void HandleAlertsY();
void HandleAlertsX();


/*------------------------------------------------------------------------------
 * Main
 *
 *    Main loop, reads analog input of SUM, deltaX, deltaY
 *	  checks if laser position is within x and y tolerance
 *    calls move motor if out of tolerance, alternates starting with x and y
 *    adjusts every 0.75 second.
 *    
 *
 * Parameters:
 *    None
 *
 * Returns: 
 *    None
 -----------------------------------------------------------------------------*/
 int main() {

    // Set the resolution of the ADC.
    AdcMgr.AdcResolution(adcResolution);
	inputPin.Mode(Connector::INPUT_DIGITAL);
	
	//Motor config
	MotorMgr.MotorInputClocking(MotorManager::CLOCK_RATE_NORMAL);
	MotorMgr.MotorModeSet(MotorManager::MOTOR_ALL, Connector::CPM_MODE_STEP_AND_DIR);
	motorX.HlfbMode(MotorDriver::HLFB_MODE_HAS_BIPOLAR_PWM);
	motorY.HlfbMode(MotorDriver::HLFB_MODE_HAS_BIPOLAR_PWM);
	motorX.HlfbCarrier(MotorDriver::HLFB_CARRIER_482_HZ);
	motorY.HlfbCarrier(MotorDriver::HLFB_CARRIER_482_HZ);
	motorX.VelMax(velocityLimit);
	motorY.VelMax(velocityLimit);
	motorX.AccelMax(accelerationLimit);
	motorY.AccelMax(accelerationLimit);
	motorX.EnableRequest(false);
	motorY.EnableRequest(false);
	

    double inputVoltageSUM, inputVoltageY, inputVoltageX, SumX, SumY, SumSum, voltageX, voltageY, voltageSum = 0.0; //tracks voltages
    bool LevelFlag, ledState = false;	//Used to set level position of first iteration of loop
    double LevelX, LevelY, Xpos, Ypos = 0.0; //used to track the desired voltages when leveling is activated
	double delay = 75; //Sets the amount of time in milliseconds before the next sample
	int num_samples = 10; //Sets the number of samples taken for the average
	int count = 0; //takes 10 samples then computes the average
	const double Xtol = 1.5E-2; // X axis tolerance
	const double Ytol = 1.5E-2; // Y axis tolerance
	const double deltaY = 2E-4; // Steps for smallest delta voltage
	const double deltaX = 2E-4; // Steps for smallest delta voltage
	
    int16_t adcSUM, adcY, adcX = 0; //adc read values
 
    while (true) {
		
		//update the leveling switch state
		leveling = inputPin.State(); 
		
        // Read the analog input (A-9 through A-12 may be configured as analog inputs).
		
        adcSUM = ConnectorA12.State();
        // Convert the reading to a voltage.
        voltageSum = 10.0 * adcSUM / ((1 << adcResolution) - 1);
        
        adcY = ConnectorA10.State();
        // Convert the reading to a voltage.
        voltageY = 10.0 * adcY / ((1 << adcResolution) - 1);
        
        adcX = ConnectorA11.State();
        // Convert the reading to a voltage.
        voltageX = 10.0 * adcX / ((1 << adcResolution) - 1);
		
		//Collect 10 voltage samples for Sum, X, and Y
		SumX += voltageX;
		SumY += voltageY;
		SumSum += voltageSum;
		
		if(count == num_samples)
		{
			//Compute the average for each voltage and set sum back to zero
			inputVoltageX = SumX/num_samples;
			inputVoltageY = SumY/num_samples;
			inputVoltageSUM =  SumSum/num_samples;
			SumY = 0;
			SumX = 0;
			SumSum = 0;
			count = 0;

			if (leveling) 
			{	//Once switch has been set to the on position the bed is level, enter automated leveling state
				
				//enable motors when leveling, this will disable manual adjustments and turn on motors.
				motorX.EnableRequest(true);
				motorY.EnableRequest(true);
				
				Xpos = inputVoltageX;	//New laser position for X
				Ypos = inputVoltageY;	//New laser position for Y
				
				if(inputVoltageSUM < 2.5) //Check if laser is still on the sensor, if not don't adjust and blink connector LED
				{
					ConnectorLed.State(ledState);
					ledState = !ledState;
				}
				
				
				else if (LevelFlag==false) 
				{	//If level flag is false create level position for reference to new level data and set flag to true
					LevelX = inputVoltageX;	//Set LevelX sensor position
					LevelY = inputVoltageY;	//Set LevelY sensor position
					LevelFlag = true; //set flag to true as to not rewrite the leveled voltages
				}

				else 
				{
					//Make X and Y adjustments if new x or y position is not within tolerance of the leveled values
					
					if ((Xpos > (LevelX + Xtol)) || (Xpos < (LevelX - Xtol))) 
					{ // If Xpos is greater than LevelX + Xtol or less than LevelX - Xtol
						MoveDistanceX(int32_t((LevelX - Xpos) / deltaX));
					} 
					
					if ((Ypos > (LevelY + Ytol))|| Ypos < (LevelY - Ytol)) 
					{ // If Ypos is greater than LevelY + Ytol or less than LevelY - Ytol
						MoveDistanceY(int32_t((Ypos - LevelY) / deltaY));
					} 
				
				} 
			}
	
			else 
			{
				LevelFlag = false; //If switch is off reset LevelFlag
				
				//Disable motors to allow for manual adjustment
				motorX.EnableRequest(false);
				motorY.EnableRequest(false);
			} 
		}
		count += 1;			//increase count to take 10 samples
		Delay_ms(delay);		// Wait a .075 second before the next reading.
	}
}
 



 
/*------------------------------------------------------------------------------
 * MoveDistanceX
 *
 *    Command "distance" number of step pulses away from the current position
 *    Returns when HLFB asserts (indicating the motorX has reached the commanded
 *    position)
 *
 * Parameters:
 *    int distance  - The distance, in step pulses, to move
 *
 * Returns: True/False depending on whether the move was successfully triggered.
 -------------------------------------------------------------------------------*/

void MoveDistanceX(int32_t distance) {
    // Check if a motorX alert is currently preventing motion
    // Clear alert if configured to do so 
     if (motorX.StatusReg().bit.AlertsPresent) 
	 {
         if(HANDLE_ALERTS)
		 {
             HandleAlertsX();
         } 
     }
 
    // Command the move of incremental distance
    motorX.Move(distance);
 
    // Waits for HLFB to assert (signaling the move has successfully completed)
    while ( (!motorX.StepsComplete() || motorX.HlfbState() != MotorDriver::HLFB_ASSERTED) &&
            !motorX.StatusReg().bit.AlertsPresent) {
        continue;
    }
   
}

void MoveDistanceY(int32_t distance) {
    // Check if a motorY alert is currently preventing motion
    // Clear alert if configured to do so 
     if (motorY.StatusReg().bit.AlertsPresent) 
	 {
		if(HANDLE_ALERTS)
		{
			HandleAlertsY();
        } 
    }
 
    // Command the move of incremental distance
    motorY.Move(distance);
 
    // Waits for HLFB to assert (signaling the move has successfully completed)
    while ( (!motorY.StepsComplete() || motorY.HlfbState() != MotorDriver::HLFB_ASSERTED) &&
            !motorY.StatusReg().bit.AlertsPresent) {
        continue;
    }
}

/*------------------------------------------------------------------------------
 * HandleAlerts
 *
 *    If a motor alert is present disable motor and wait for alert to clear
 *	  then re-enable the motor before making adjustment.
 *
 * Parameters:
 *    None
 *
 * Returns: Nothing
 -------------------------------------------------------------------------------*/
void HandleAlertsX(){
	if(motorX.AlertReg().bit.MotorFaulted){
		motorX.EnableRequest(false);
		Delay_ms(10);
		motorX.EnableRequest(true);
	}
	motorX.ClearAlerts();
}

void HandleAlertsY(){
	if(motorY.AlertReg().bit.MotorFaulted){
		motorY.EnableRequest(false);
		Delay_ms(10);
		motorY.EnableRequest(true);
	}
	motorY.ClearAlerts();
}

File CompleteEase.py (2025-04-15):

import numpy as np
import matplotlib.pyplot as plt
import glob

# === CONFIG ===
cutoff = 25               # Time cutoff in minutes
num_points = 300          # Number of points for interpolation
data_dir = "EllipsometerLevelData"

# === LOAD BASELINES ===
baseline_motor = np.genfromtxt(f"{data_dir}/dynamic data.txt", delimiter='\t', skip_header=2, filling_values=np.nan)
baseline_adjustment = np.genfromtxt(f"{data_dir}/NoAdjustment.txt", delimiter='\t', skip_header=2, filling_values=np.nan)

# Extract and trim "No Motor" baseline
time_motor = baseline_motor[:, 0]
align_x_motor = baseline_motor[:, 1]
align_y_motor = baseline_motor[:, 2]
mask_motor = time_motor <= cutoff
time_motor = time_motor[mask_motor]
align_x_motor = align_x_motor[mask_motor]
align_y_motor = align_y_motor[mask_motor]

# Extract "No Adjustment" baseline
time_adjustment = baseline_adjustment[:, 0]
align_x_adjustment = baseline_adjustment[:, 1]
align_y_adjustment = baseline_adjustment[:, 2]

# === LOAD RUN DATA FILES ===
run_files = sorted(glob.glob(f"{data_dir}/Ellip_test*.txt"))
common_time = np.linspace(0, cutoff, num_points)
all_align_x, all_align_y = [], []

for file in run_files:
    data = np.genfromtxt(file, delimiter='\t', skip_header=2, filling_values=np.nan)
    time = data[:, 0]
    align_x = data[:, 1]
    align_y = data[:, 2]

    # Clip to cutoff
    mask = time <= cutoff
    time = time[mask]
    align_x = align_x[mask]
    align_y = align_y[mask]

    # Interpolate to common time base
    interp_x = np.interp(common_time, time, align_x)
    interp_y = np.interp(common_time, time, align_y)

    all_align_x.append(interp_x)
    all_align_y.append(interp_y)

# Convert to arrays for averaging
all_align_x = np.array(all_align_x)
all_align_y = np.array(all_align_y)
avg_align_x = np.mean(all_align_x, axis=0)
avg_align_y = np.mean(all_align_y, axis=0)

# === PLOT ALIGNX AND ALIGNY ===
fig, (ax1, ax2) = plt.subplots(2, 1, figsize=(12, 8), sharex=True)

# --- ALIGN X ---
ax1.plot(time_motor, align_x_motor, label='No Motor', color='red')
ax1.plot(time_adjustment, align_x_adjustment, label='No Adjustment', color='blue')
for i, run in enumerate(all_align_x):
    ax1.plot(common_time, run, alpha=0.4, label=f'Run {i+1}')
ax1.plot(common_time, avg_align_x, color='black', linewidth=2, label='Average')
ax1.set_ylabel('AlignX')
ax1.set_title('AlignX vs Time')
ax1.legend(loc='upper right')
ax1.grid(True)

# --- ALIGN Y ---
ax2.plot(time_motor, align_y_motor, label='No Motor', color='red')
ax2.plot(time_adjustment, align_y_adjustment, label='No Adjustment', color='blue')
for i, run in enumerate(all_align_y):
    ax2.plot(common_time, run, alpha=0.4, label=f'Run {i+1}')
ax2.plot(common_time, avg_align_y, color='black', linewidth=2, label='Average')
ax2.set_xlabel('Time (min.)')
ax2.set_ylabel('AlignY')
ax2.set_title('AlignY vs Time')
ax2.legend(loc='upper right')
ax2.grid(True)

plt.tight_layout()
plt.show()

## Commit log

2025-03-27 Working motors small tweak in postition logic at check X
2025-03-27 Working System, No Latteral-effect sensor
2025-04-01 set X and Y tolerances
    [SeniorProject.cpp]
2025-04-02 Working system Y a little gittery, will try an average filter on inputs for more stable response.
2025-04-02 Error being introduced into the system. Going to reevaluate with averaged sum every time.
    [SeniorProject.cpp]
2025-04-15 Added files for final documentation and reference
    [AdjustmentKnob.stl, Ellip_test10_serial.csv, Ellip_test5_serial.csv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]
